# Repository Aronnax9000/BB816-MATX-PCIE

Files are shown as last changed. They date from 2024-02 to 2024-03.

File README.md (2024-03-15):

# BB816-PCIe
Adapt Adrien Kohlbecker's BB816 Breakout Board to PCIExpress x16 style connector.

Four slots for expansion cards based on PCIe geometry and the mATX Specification. A 20 pin ATX power supply connector is provided. The board is made to the same specifications as Adrien Kohlbecker's BB816

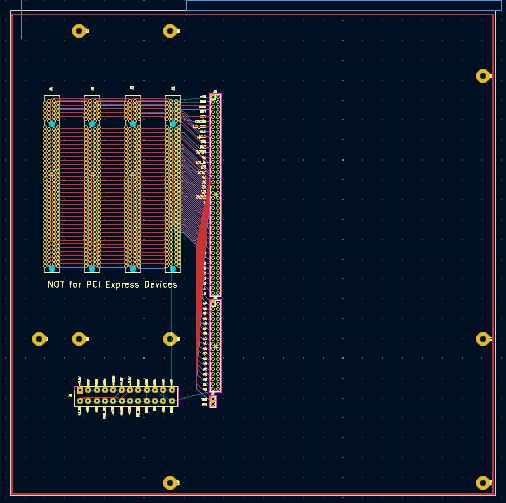
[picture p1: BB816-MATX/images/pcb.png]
Backplane


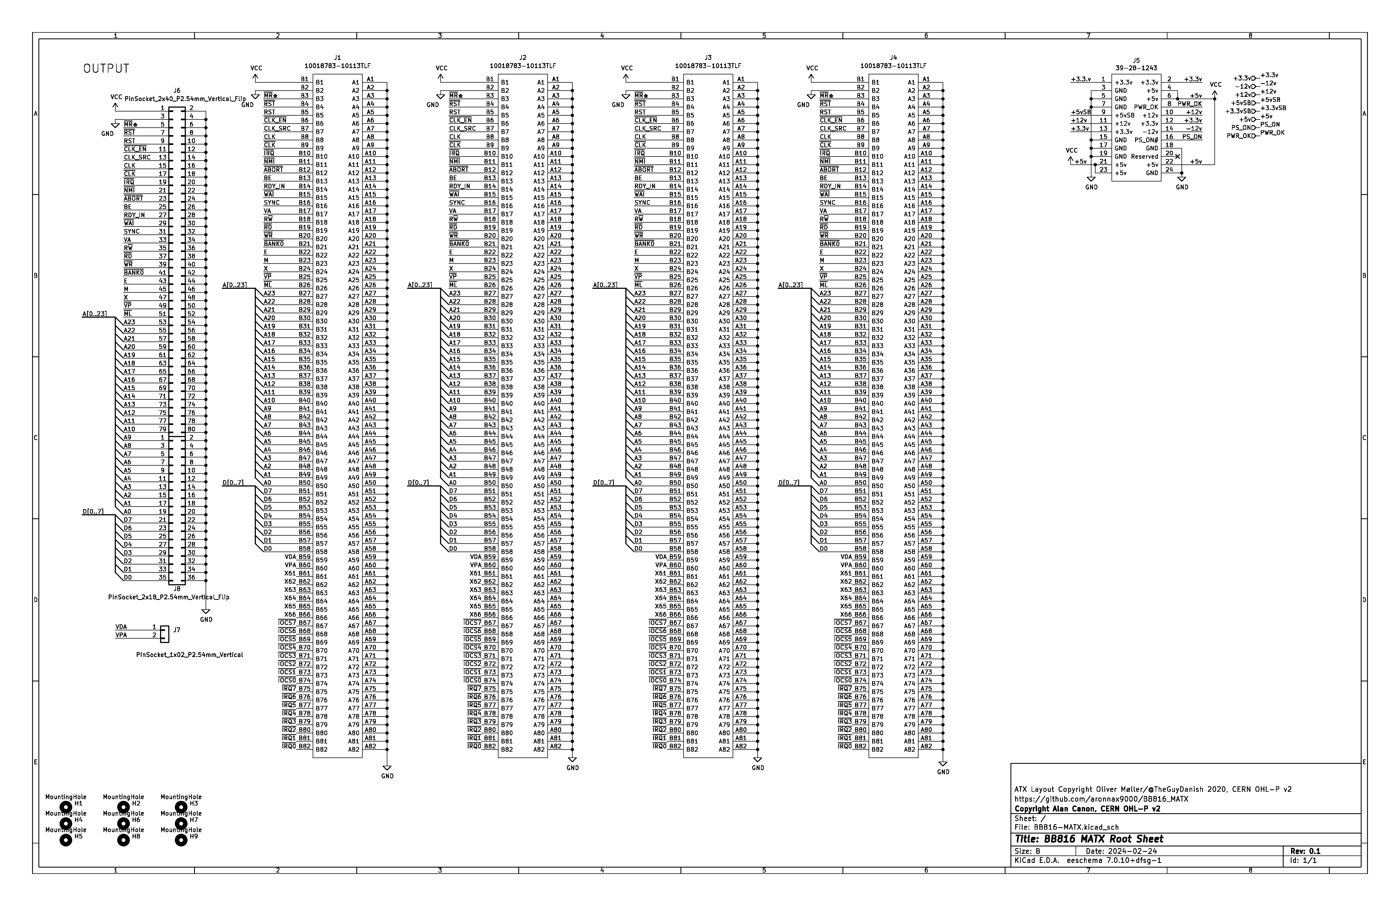
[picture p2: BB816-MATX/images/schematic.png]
Backplane Scematic


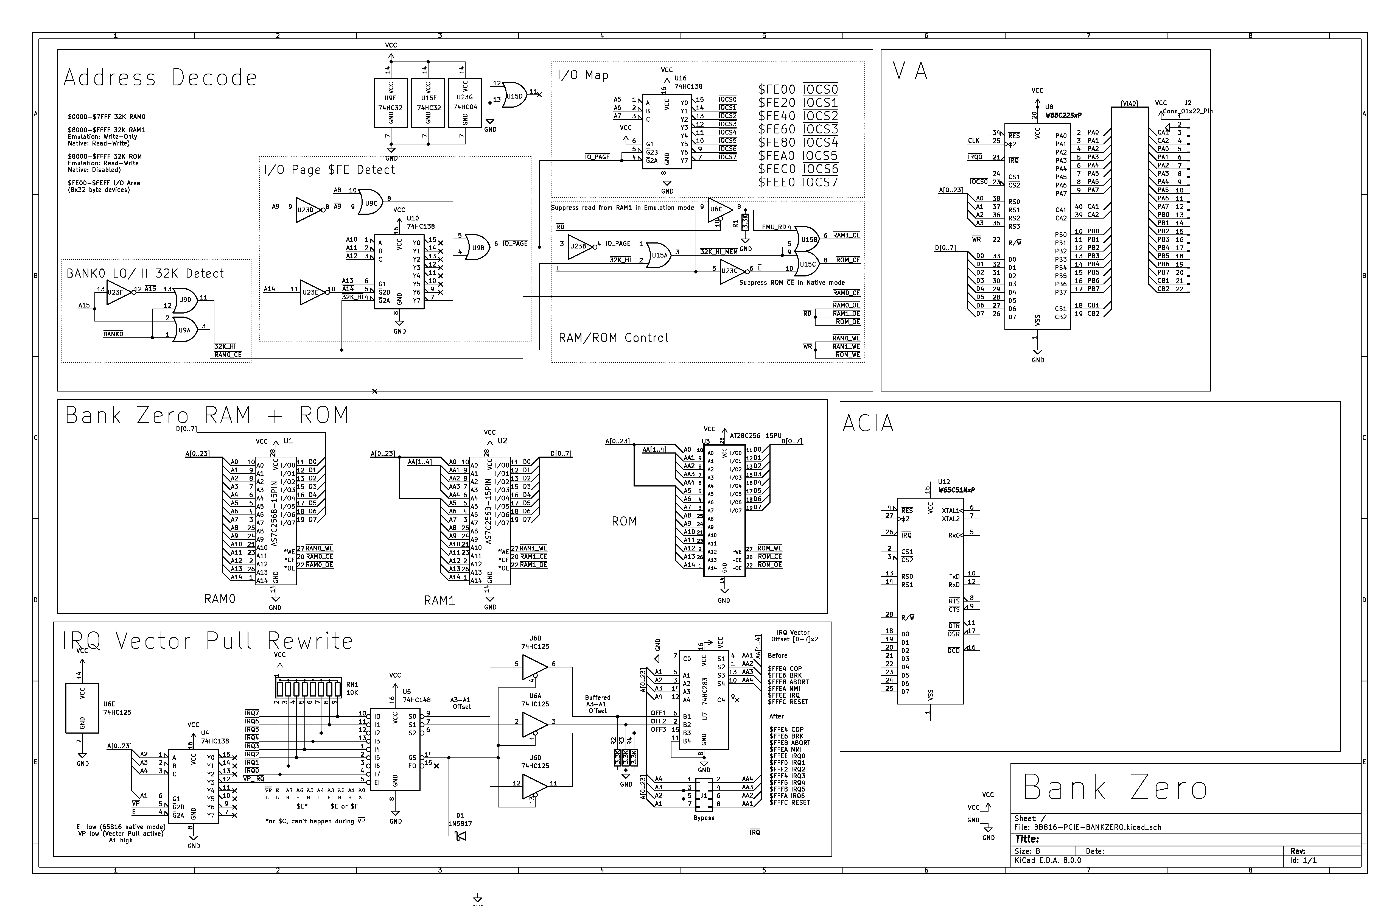
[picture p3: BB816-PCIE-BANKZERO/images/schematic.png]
Schematic


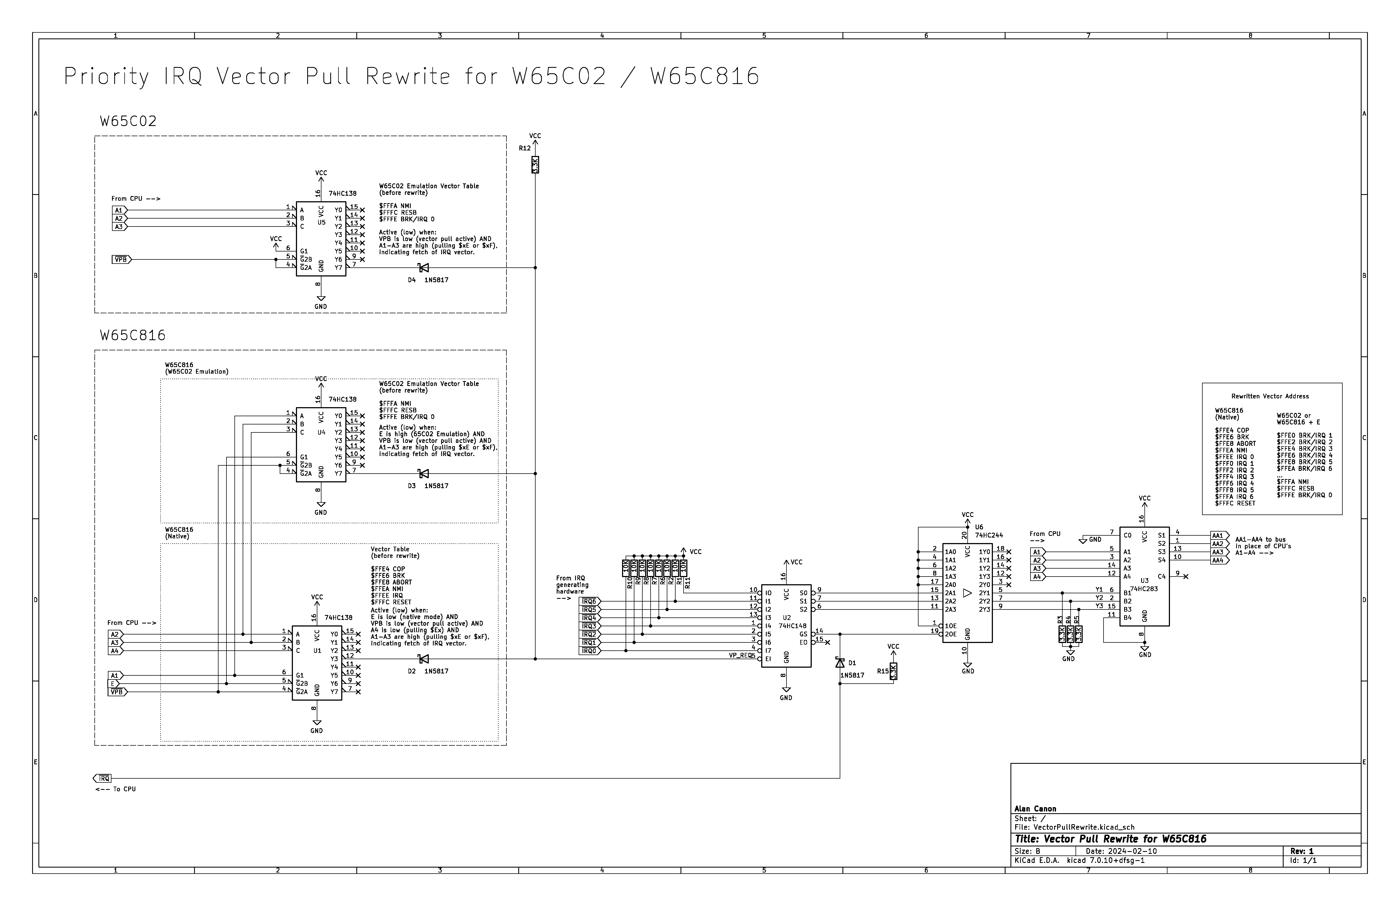
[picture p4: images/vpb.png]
VectorPullRewrite


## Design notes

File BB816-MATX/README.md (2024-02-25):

# BB816-MATX

A mATX (Micro-ATX) form factor system board for Adrien Kohlbecker's [BB816](https://github.com/adrienkohlbecker/BB816) Breakout Board, rev. A27.

This project adapts an [ATX layout](https://github.com/theguydanish/CM4_MATX) created by Oliver Møller for the (archived) CM4_MATX project.

In addition to the breakout board connector, the system board provides four bus connectors of the type used for PCIExpress x16 add-on cards, and an ATX power supply connector. 

Schematic

PCB

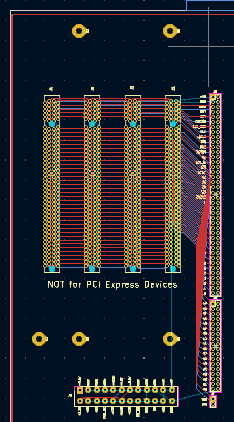
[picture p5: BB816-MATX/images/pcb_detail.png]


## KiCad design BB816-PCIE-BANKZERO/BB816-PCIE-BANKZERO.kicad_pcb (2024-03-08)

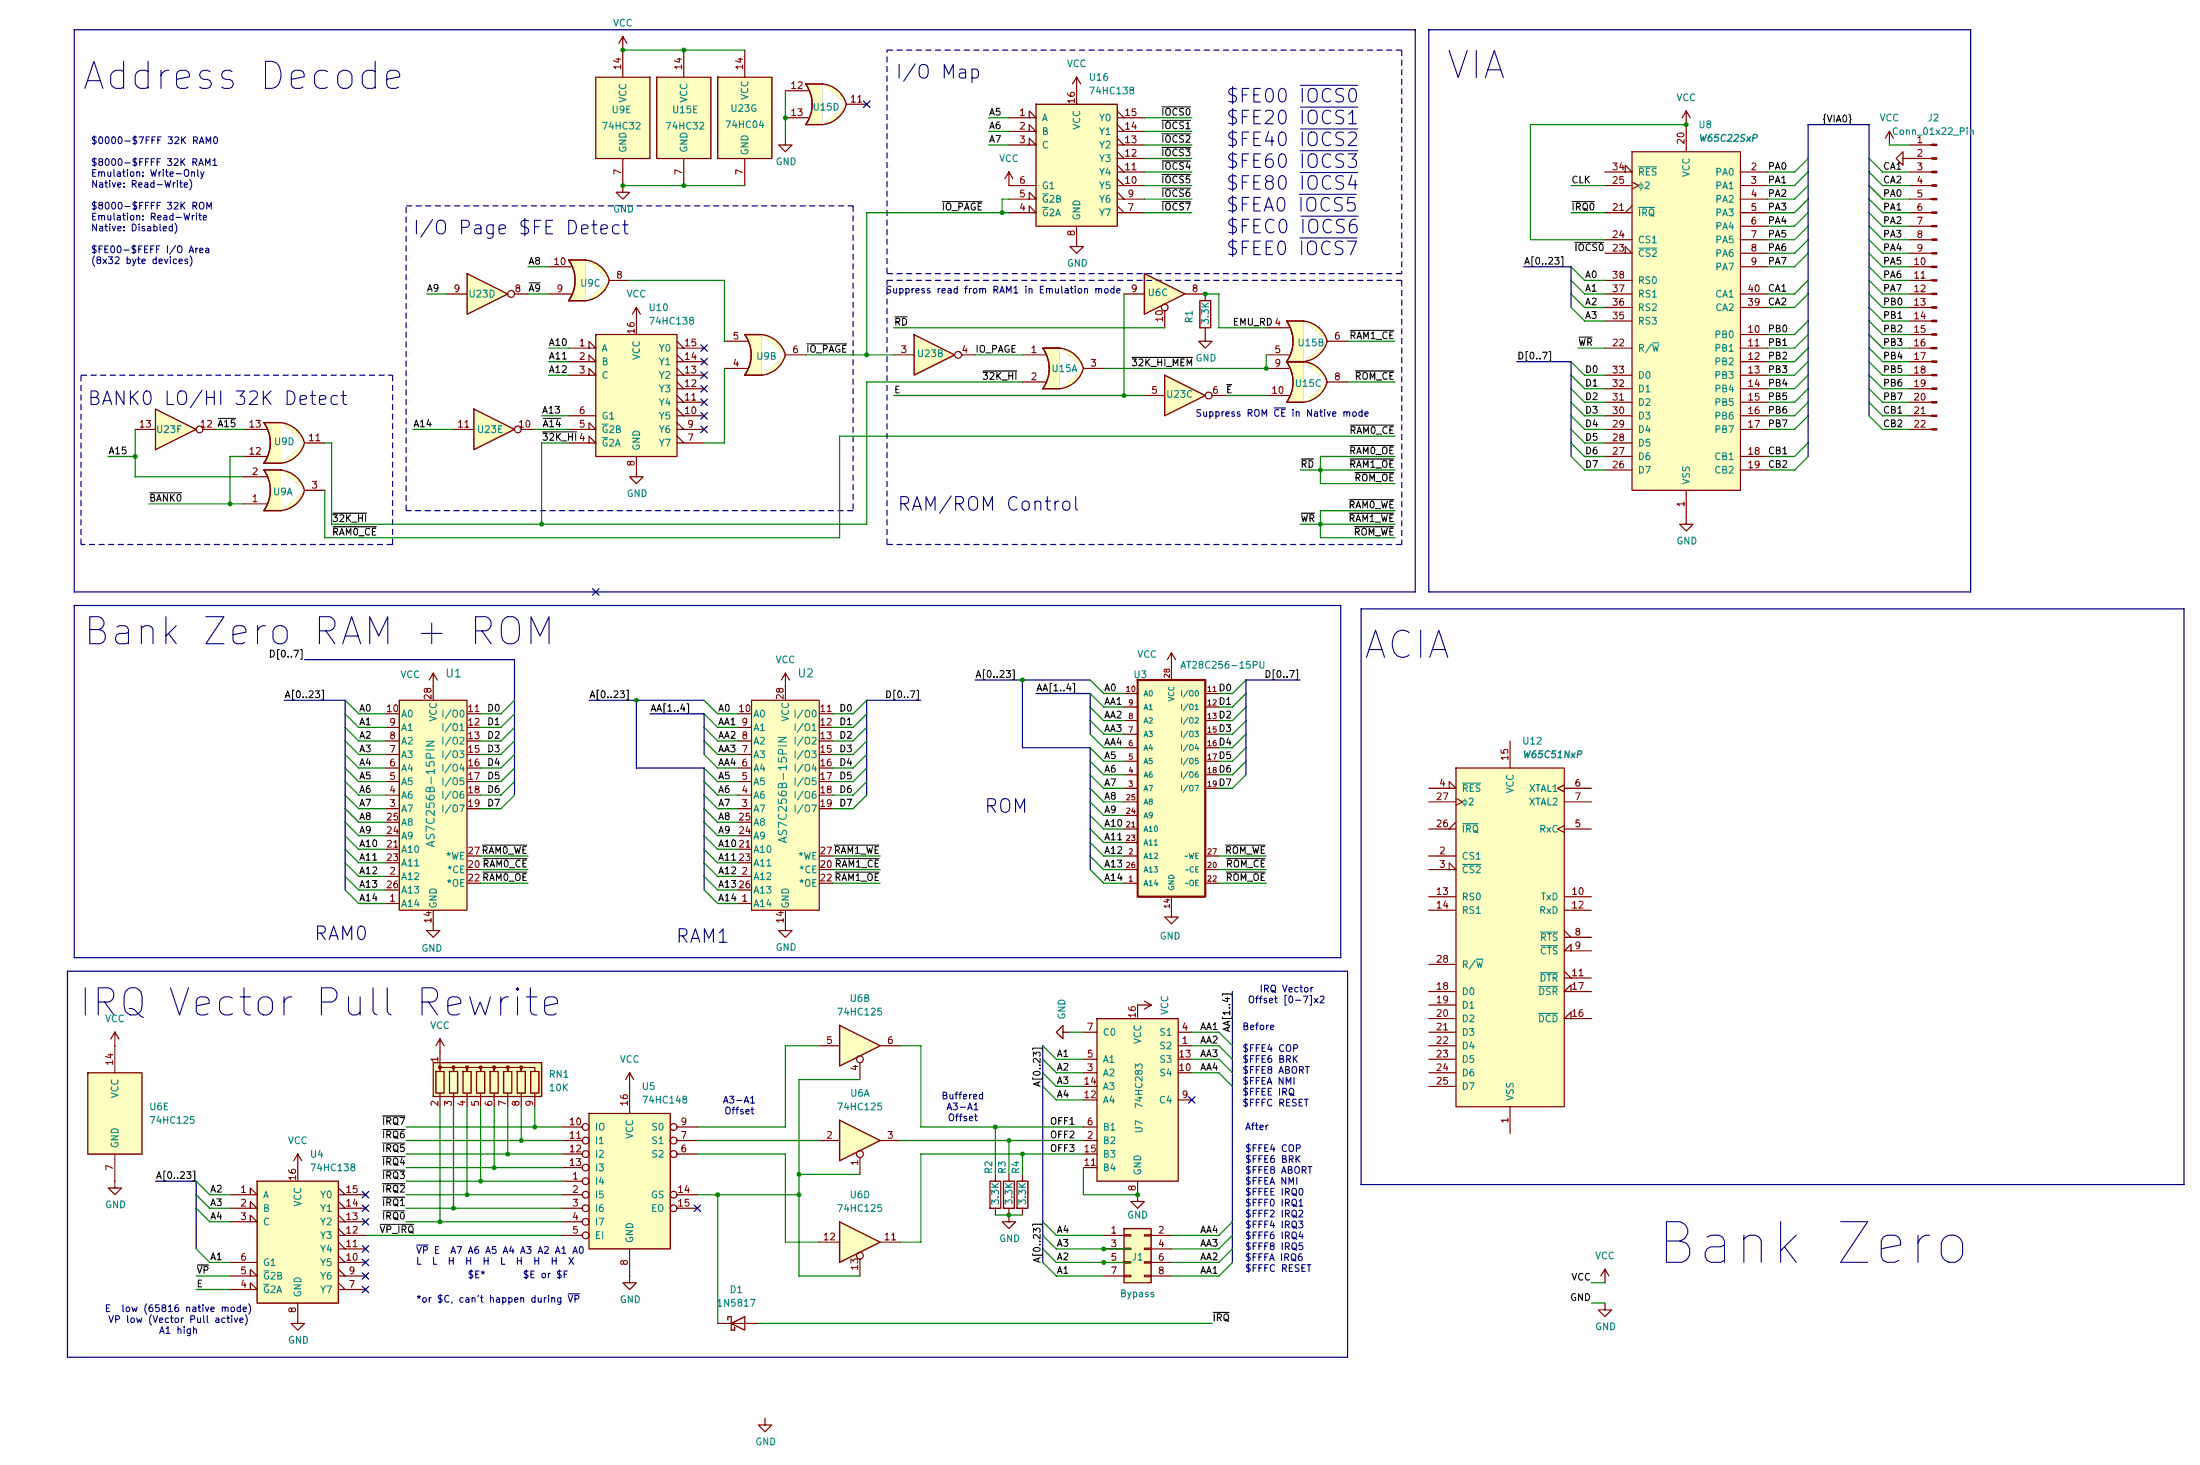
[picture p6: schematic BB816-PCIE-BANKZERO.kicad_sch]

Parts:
D1: 1N5817; D_DO-41_SOD81_P10.16mm_Horizontal
J1: Bypass; PinHeader_2x04_P2.54mm_Vertical
J2: Conn_01x22_Pin; PinSocket_1x22_P2.54mm_Horizontal
R1, R2, R3, R4: 3.3K; R_Axial_DIN0207_L6.3mm_D2.5mm_P7.62mm_Horizontal
RN1: 10K; R_Array_SIP9
U1, U2: AS7C256B-15PIN; DIP-28_W7.62mm_Socket
U3: AT28C256-15PU; 228-1277-00-0602J_3MM; MPN AT28C256-15PU
U4, U10, U16: 74HC138; DIP-16_W7.62mm_Socket
U5: 74HC148; DIP-16_W7.62mm_Socket
U6: 74HC125; DIP-14_W7.62mm_Socket
U7: 74HC283; DIP-16_W7.62mm_Socket
U8: W65C22SxP; DIP-40_W15.24mm_Socket
U9, U15: 74HC32; DIP-14_W7.62mm_Socket
U12: W65C51NxP; DIP-28_W15.24mm_Socket
U23: 74HC04; DIP-14_W7.62mm_Socket

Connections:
/A0: U1.10 (A0), U2.10 (A0), U3.10 (A0), U8.38 (RS0)
/A1: J1.7, U1.9 (A1), U4.6 (G1), U7.5 (A1), U8.37 (RS1)
/A2: J1.5, U1.8 (A2), U4.1 (A), U7.3 (A2), U8.36 (RS2)
/A3: J1.3, U1.7 (A3), U4.2 (B), U7.14 (A3), U8.35 (RS3)
/A4: J1.1, U1.6 (A4), U4.3 (C), U7.12 (A4)
/A5: U1.5 (A5), U2.5 (A5), U3.5 (A5), U16.1 (A)
/A6: U1.4 (A6), U2.4 (A6), U3.4 (A6), U16.2 (B)
/A7: U1.3 (A7), U2.3 (A7), U3.3 (A7), U16.3 (C)
/A8: U1.25 (A8), U2.25 (A8), U3.25 (A8), U9.10
/A9: U1.24 (A9), U2.24 (A9), U3.24 (A9), U23.9
/A10: U1.21 (A10), U2.21 (A10), U3.21 (A10), U10.1 (A)
/A11: U1.23 (A11), U2.23 (A11), U3.23 (A11), U10.2 (B)
/A12: U1.2 (A12), U2.2 (A12), U3.2 (A12), U10.3 (C)
/A13: U1.26 (A13), U2.26 (A13), U3.26 (A13), U10.6 (G1)
/A14: U1.1 (A14), U2.1 (A14), U3.1 (A14), U23.11
/A15: U9.2, U23.13
/AA1: J1.8, U2.9 (A1), U3.9 (A1), U7.4 (S1)
/AA2: J1.6, U2.8 (A2), U3.8 (A2), U7.1 (S2)
/AA3: J1.4, U2.7 (A3), U3.7 (A3), U7.13 (S3)
/AA4: J1.2, U2.6 (A4), U3.6 (A4), U7.10 (S4)
/CA1: J2.3, U8.40 (CA1)
/CA2: J2.4, U8.39 (CA2)
/CB1: J2.21, U8.18 (CB1)
/CB2: J2.22, U8.19 (CB2)
/CLK: U8.25 (ϕ2)
/D0: U1.11 (I/O0), U2.11 (I/O0), U3.11 (I/O0), U8.33 (D0)
/D1: U1.12 (I/O1), U2.12 (I/O1), U3.12 (I/O1), U8.32 (D1)
/D2: U1.13 (I/O2), U2.13 (I/O2), U3.13 (I/O2), U8.31 (D2)
/D3: U1.15 (I/O3), U2.15 (I/O3), U3.15 (I/O3), U8.30 (D3)
/D4: U1.16 (I/O4), U2.16 (I/O4), U3.16 (I/O4), U8.29 (D4)
/D5: U1.17 (I/O5), U2.17 (I/O5), U3.17 (I/O5), U8.28 (D5)
/D6: U1.18 (I/O6), U2.18 (I/O6), U3.18 (I/O6), U8.27 (D6)
/D7: U1.19 (I/O7), U2.19 (I/O7), U3.19 (I/O7), U8.26 (D7)
/E: U4.4 (~G2A), U6.9, U23.5
/EMU_RD: R1.1, U6.8, U15.4
/IO_PAGE: U15.1, U23.4
/OFF1: R2.1, U6.6, U7.6 (B1)
/OFF2: R3.1, U6.3, U7.2 (B2)
/OFF3: R4.1, U6.11, U7.15 (B3)
/PA0: J2.5, U8.2 (PA0)
/PA1: J2.6, U8.3 (PA1)
/PA2: J2.7, U8.4 (PA2)
/PA3: J2.8, U8.5 (PA3)
/PA4: J2.9, U8.6 (PA4)
/PA5: J2.10, U8.7 (PA5)
/PA6: J2.11, U8.8 (PA6)
/PA7: J2.12, U8.9 (PA7)
/PB0: J2.13, U8.10 (PB0)
/PB1: J2.14, U8.11 (PB1)
/PB2: J2.15, U8.12 (PB2)
/PB3: J2.16, U8.13 (PB3)
/PB4: J2.17, U8.14 (PB4)
/PB5: J2.18, U8.15 (PB5)
/PB6: J2.19, U8.16 (PB6)
/PB7: J2.20, U8.17 (PB7)
/~32K_HI_MEM: U15.3, U15.5, U15.9
/~32K_HI: U9.11, U10.4 (~G2A), U15.2
/~A9: U9.9, U23.8
/~A14: U10.5 (~G2B), U23.10
/~A15: U9.13, U23.12
/~BANK0: U9.1, U9.12
/~E: U15.10, U23.6
/~IOCS0: U8.23 (~CS2), U16.15 (Y0)
/~IOCS1: U16.14 (Y1)
/~IOCS2: U16.13 (Y2)
/~IOCS3: U16.12 (Y3)
/~IOCS4: U16.11 (Y4)
/~IOCS5: U16.10 (Y5)
/~IOCS6: U16.9 (Y6)
/~IOCS7: U16.7 (Y7)
/~IO_PAGE: U9.6, U16.4 (~G2A), U16.5 (~G2B), U23.3
/~IRQ0: RN1.2 (R1), U5.4 (I7), U8.21 (~IRQ)
/~IRQ1: RN1.3 (R2), U5.3 (I6)
/~IRQ2: RN1.4 (R3), U5.2 (I5)
/~IRQ3: RN1.5 (R4), U5.1 (I4)
/~IRQ4: RN1.6 (R5), U5.13 (I3)
/~IRQ5: RN1.7 (R6), U5.12 (I2)
/~IRQ6: RN1.8 (R7), U5.11 (I1)
/~IRQ7: RN1.9 (R8), U5.10 (IO)
/~IRQ: D1.2 (A)
/~RAM0_CE: U1.20 (*CE), U9.3
/~RAM0_OE: U1.22 (*OE), U2.22 (*OE), U3.22 (~OE), U6.10
/~RAM0_WE: U1.27 (*WE), U2.27 (*WE), U3.27 (~WE), U8.22 (R/~W)
/~RAM1_CE: U2.20 (*CE), U15.6
/~ROM_CE: U3.20 (~CE), U15.8
/~VP_IRQ: U4.12 (Y3), U5.5 (EI)
/~VP: U4.5 (~G2B)
GND: J2.2, R1.2, R2.2, R3.2, R4.2, U1.14 (GND), U2.14 (GND), U3.14 (GND), U4.8 (GND), U5.8 (GND), U6.7 (GND), U7.7 (C0), U7.8 (GND), U7.11 (B4), U8.1 (VSS), U9.7 (GND), U10.8 (GND), U15.7 (GND), U15.12, U15.13, U16.8 (GND), U23.7 (GND)
unnamed: D1.1 (K), U5.14 (GS), U6.1, U6.4, U6.13
unnamed: U5.9 (S0), U6.5
unnamed: U5.7 (S1), U6.2
unnamed: U5.6 (S2), U6.12
unnamed: U9.5, U9.8
unnamed: U9.4, U10.7 (Y7)
VCC: J2.1, RN1.1 (common), U1.28 (VCC), U2.28 (VCC), U3.28 (VCC), U4.16 (VCC), U5.16 (VCC), U6.14 (VCC), U7.16 (VCC), U8.20 (VCC), U8.24 (CS1), U9.14 (VCC), U10.16 (VCC), U15.14 (VCC), U16.6 (G1), U16.16 (VCC), U23.14 (VCC)

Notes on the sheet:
$E or $F
After $FFE4 COP $FFE6 BRK $FFE8 ABORT $FFEA NMI $FFEE IRQ0 $FFF0 IRQ1 $FFF2 IRQ2 $FFF4 IRQ3 $FFF6 IRQ4 $FFF8 IRQ5 $FFFA IRQ6 $FFFC RESET
IRQ Vector Pull Rewrite
ROM
E low (65816 native mode) VP low (Vector Pull active) A1 high
RAM/ROM Control
Buffered A3-A1 Offset
Suppress ROM ~{CE} in Native mode
Before $FFE4 COP $FFE6 BRK $FFE8 ABORT $FFEA NMI $FFEE IRQ $FFFC RESET
BANK0 LO/HI 32K Detect
ACIA
Address Decode
Bank Zero RAM + ROM
$E*
~{VP} E A7 A6 A5 A4 A3 A2 A1 A0 L L H H H L H H H X
VIA
$FE00 ~{IOCS0} $FE20 ~{IOCS1} $FE40 ~{IOCS2} $FE60 ~{IOCS3} $FE80 ~{IOCS4} $FEA0 ~{IOCS5} $FEC0 ~{IOCS6} $FEE0 ~{IOCS7}
Suppress read from RAM1 in Emulation mode
RAM1
Bank Zero
A3-A1 Offset
I/O Map
I/O Page $FE Detect
*or $C, can't happen during ~{VP}
$0000-$7FFF 32K RAM0 $8000-$FFFF 32K RAM1 Emulation: Write-Only Native: Read-Write) $8000-$FFFF 32K ROM Emulation: Read-Write Native: Disabled) $FE00-$FEFF I/O Area (8x32 byte devices)
RAM0
IRQ Vector Offset [0-7]x2

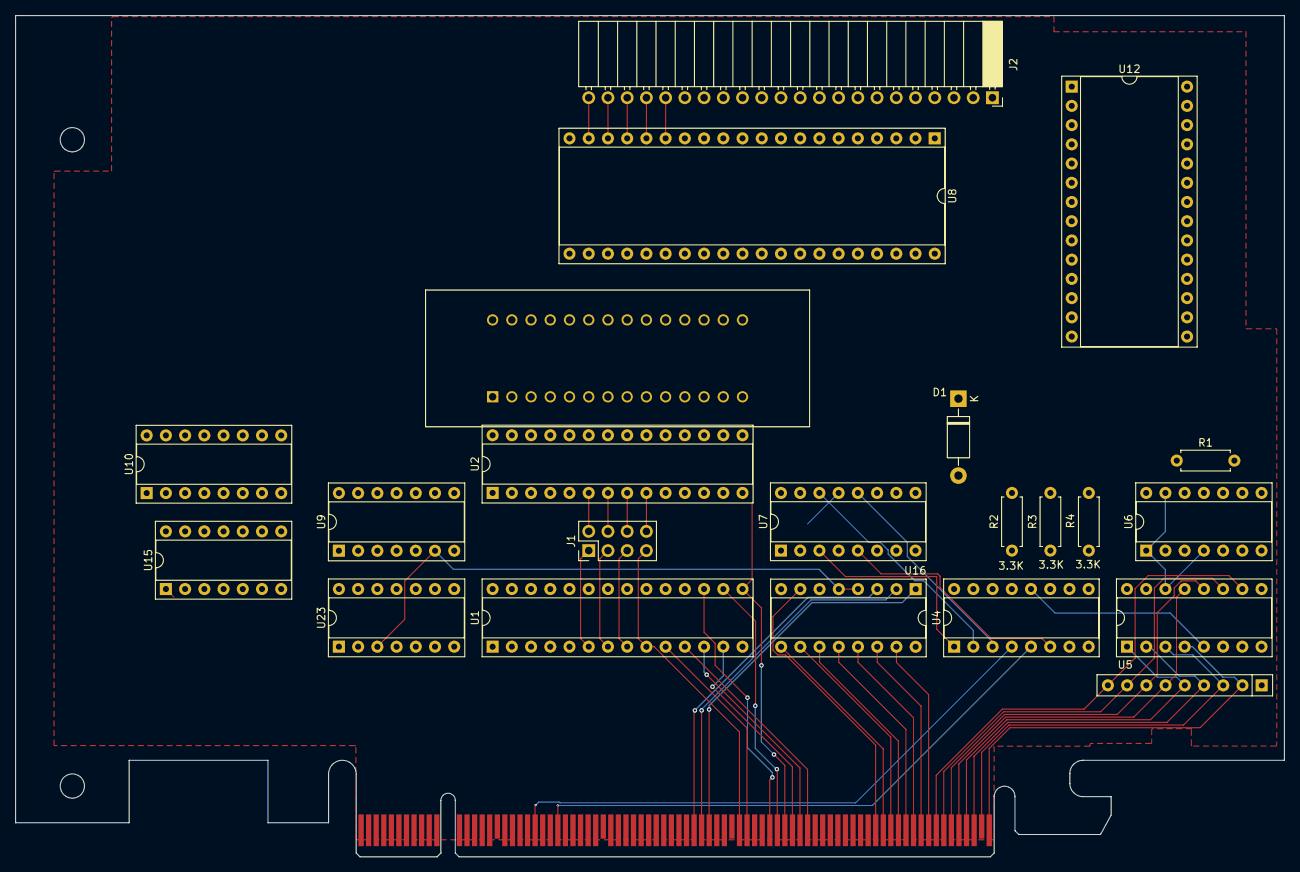
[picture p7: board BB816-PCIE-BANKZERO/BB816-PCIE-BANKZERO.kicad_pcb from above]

Board: 4 copper layers, 167.7 x 111.1 mm, 22 parts (0 on the bottom side), 85 nets.

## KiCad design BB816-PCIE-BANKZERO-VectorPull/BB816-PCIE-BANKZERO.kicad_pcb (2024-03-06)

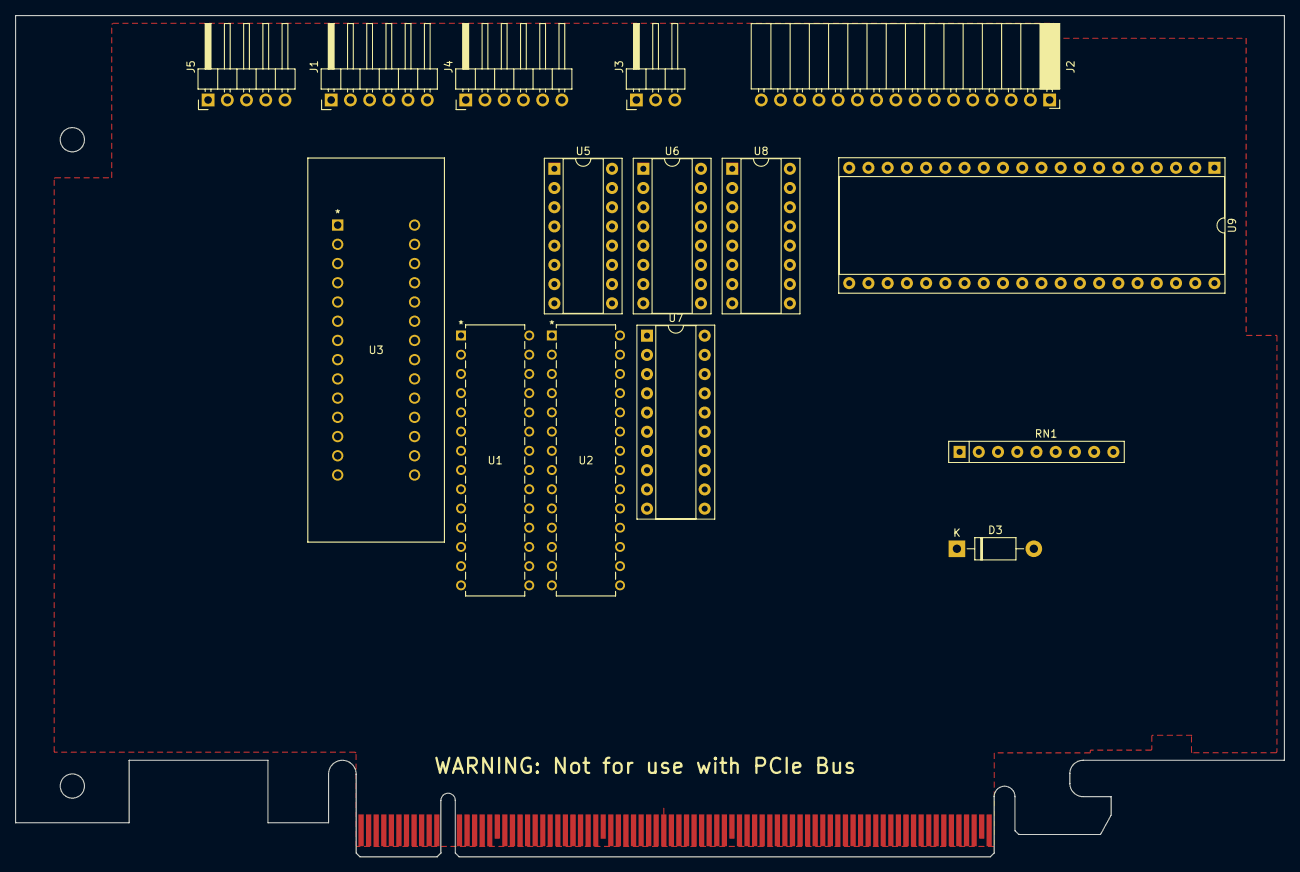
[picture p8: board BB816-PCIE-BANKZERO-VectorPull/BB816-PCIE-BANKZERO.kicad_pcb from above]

Board: 4 copper layers, 167.6 x 111.2 mm, 16 parts (0 on the bottom side), 58 nets.

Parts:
D3: 1N5817; D_DO-41_SOD81_P10.16mm_Horizontal
J1: SPI_0; PinHeader_1x06_P2.54mm_Horizontal
J1#2: BB816_BreakoutA27_PCIex16; PCIexpress_x16_HW_FH
J2: LCD Display; PinSocket_1x16_P2.54mm_Horizontal
J3: LCD Backlight; PinHeader_1x03_P2.54mm_Horizontal
J4: SPI_1; PinHeader_1x06_P2.54mm_Horizontal
J5: GPIO; PinHeader_1x05_P2.54mm_Horizontal
RN1: 10K; R_Array_SIP9
U1, U2: AS7C256B-15PIN; PDIP-28_MIL300_ALL
U3: AT28C256-15PU; 228-1277-00-0602J_3MM
U5: 74HC138; DIP-16_W7.62mm_Socket
U6: 74HC148; DIP-16_W7.62mm_Socket
U7: 74HC244; DIP-20_W7.62mm_Socket
U8: 74HC283; DIP-16_W7.62mm_Socket
U9: W65C22SxP; DIP-40_W15.24mm_Socket

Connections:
/A0: J1#2.B50 (A0), U1.10 (A0), U2.10 (A0), U3.10 (A0), U9.38 (RS0)
/A1: J1#2.B49 (A1), U1.9 (A1), U5.6 (G1), U8.5 (A1), U9.37 (RS1)
/A2: J1#2.B48 (A2), U1.8 (A2), U5.1 (A), U8.3 (A2), U9.36 (RS2)
/A3: J1#2.B47 (A3), U1.7 (A3), U5.2 (B), U8.14 (A3), U9.35 (RS3)
/A4: J1#2.B46 (A4), U1.6 (A4), U5.3 (C), U8.12 (A4)
/A5: J1#2.B45 (A5), U1.5 (A5), U2.5 (A5), U3.5 (A5)
/A6: J1#2.B44 (A6), U1.4 (A6), U2.4 (A6), U3.4 (A6)
/A7: J1#2.B43 (A7), U1.3 (A7), U2.3 (A7), U3.3 (A7)
/A8: J1#2.B42 (A8), U1.25 (A8), U2.25 (A8), U3.25 (A8)
/A9: J1#2.B41 (A9), U1.24 (A9), U2.24 (A9), U3.24 (A9)
/A10: J1#2.B40 (A10), U1.21 (A10), U2.21 (A10), U3.21 (A10)
/A11: J1#2.B39 (A11), U1.23 (A11), U2.23 (A11), U3.23 (A11)
/A12: J1#2.B38 (A12), U1.2 (A12), U2.2 (A12), U3.2 (A12)
/A13: J1#2.B37 (A13), U1.26 (A13), U2.26 (A13), U3.26 (A13)
/A14: J1#2.B36 (A14), U1.1 (A14), U2.1 (A14), U3.1 (A14)
/AA1: U2.9 (A1), U3.9 (A1), U8.4 (S1)
/AA2: U2.8 (A2), U3.8 (A2), U8.1 (S2)
/AA3: U2.7 (A3), U3.7 (A3), U8.13 (S3)
/AA4: U2.6 (A4), U3.6 (A4), U8.10 (S4)
/CLK: J1#2.B8 (CLK), U9.25 (ϕ2)
/D0: J1#2.B58 (D0), U1.11 (I/O0), U2.11 (I/O0), U3.19 (I/O7), U9.33 (D0)
/D1: J1#2.B57 (D1), U1.12 (I/O1), U2.12 (I/O1), U3.18 (I/O6), U9.32 (D1)
/D2: J1#2.B56 (D2), U1.13 (I/O2), U2.13 (I/O2), U3.17 (I/O5), U9.31 (D2)
/D3: J1#2.B55 (D3), U1.15 (I/O3), U2.15 (I/O3), U3.16 (I/O4), U9.30 (D3)
/D4: J1#2.B54 (D4), U1.16 (I/O4), U2.16 (I/O4), U3.15 (I/O3), U9.29 (D4)
/D5: J1#2.B53 (D5), U1.17 (I/O5), U2.17 (I/O5), U3.13 (I/O2), U9.28 (D5)
/D6: J1#2.B52 (D6), U1.18 (I/O6), U2.18 (I/O6), U3.12 (I/O1), U9.27 (D6)
/D7: J1#2.B51 (D7), U1.19 (I/O7), U2.19 (I/O7), U3.11 (I/O0), U9.26 (D7)
/E: J1#2.B22 (E), U5.5 (~G2B)
/PB0: J1.3 (~CS), J2.11 (D4), U9.10 (PB0)
/PB1: J2.12 (D5), J4.3 (~CS), U9.11 (PB1)
/PB2: J1.4 (SCK), J2.13 (D6), J4.4 (SCK), U9.12 (PB2)
/PB3: J1.5 (SDI), J2.14 (D7), J4.5 (SDI), U9.13 (PB3)
/PB4: J1.6 (SDO), J2.4 (RS), J4.6 (SDO), U9.14 (PB4)
/PB5: J2.5 (R~W), J5.3, U9.15 (PB5)
/PB6: J2.6 (E), J5.4, U9.16 (PB6)
/PB7: J5.5, U9.17 (PB7)
/~IRQ0: J1#2.B82 (X82), RN1.2 (R1), U6.4 (I7)
/~IRQ1: J1#2.B81 (X81), RN1.3 (R2), U6.3 (I6)
/~IRQ2: J1#2.B80 (X80), RN1.4 (R3), U6.2 (I5)
/~IRQ3: J1#2.B79 (X79), RN1.5 (R4), U6.1 (I4)
/~IRQ4: J1#2.B78 (X78), RN1.6 (R5), U6.13 (I3)
/~IRQ5: J1#2.B77 (X77), RN1.7 (R6), U6.12 (I2)
/~IRQ6: J1#2.B76 (X76), RN1.8 (R7), U6.11 (I1)
/~IRQ7: J1#2.B75 (X75), RN1.9 (R8), U6.10 (IO)
/~IRQ: D3.2 (A), J1#2.B10 (~IRQ)
/~VP: J1#2.B25 (~VP), U5.4 (~G2A)
GND: J1.2 (GND), J1#2.A1 (GND), J1#2.A2 (GND), J1#2.A3 (GND), J1#2.A4 (GND), J1#2.A5 (GND), J1#2.A6 (GND), J1#2.A7 (GND), J1#2.A8 (GND), J1#2.A9 (GND), J1#2.A10 (GND), J1#2.A11 (GND), J1#2.A12 (GND), J1#2.A13 (GND), J1#2.A14 (GND), J1#2.A15 (GND), J1#2.A16 (GND), J1#2.A17 (GND), J1#2.A18 (GND), J1#2.A19 (GND), J1#2.A20 (GND), J1#2.A21 (GND), J1#2.A22 (GND), J1#2.A23 (GND), J1#2.A24 (GND), J1#2.A25 (GND), J1#2.A26 (GND), J1#2.A27 (GND), J1#2.A28 (GND), J1#2.A29 (GND), J1#2.A30 (GND), J1#2.A31 (GND), J1#2.A32 (GND), J1#2.A33 (GND), J1#2.A34 (GND), J1#2.A35 (GND), J1#2.A36 (GND), J1#2.A37 (GND), J1#2.A38 (GND), J1#2.A39 (GND), J1#2.A40 (GND), J1#2.A41 (GND), J1#2.A42 (GND), J1#2.A43 (GND), J1#2.A44 (GND), J1#2.A45 (GND), J1#2.A46 (GND), J1#2.A47 (GND), J1#2.A48 (GND), J1#2.A49 (GND), J1#2.A50 (GND), J1#2.A51 (GND), J1#2.A52 (GND), J1#2.A53 (GND), J1#2.A54 (GND), J1#2.A55 (GND), J1#2.A56 (GND), J1#2.A57 (GND), J1#2.A58 (GND), J1#2.A59 (GND), J1#2.A60 (GND), J1#2.A61 (GND), J1#2.A62 (GND), J1#2.A63 (GND), J1#2.A64 (GND), J1#2.A65 (GND), J1#2.A66 (GND), J1#2.A67 (GND), J1#2.A68 (GND), J1#2.A69 (GND), J1#2.A70 (GND), J1#2.A71 (GND), J1#2.A72 (GND), J1#2.A73 (GND), J1#2.A74 (GND), J1#2.A75 (GND), J1#2.A76 (GND), J1#2.A77 (GND), J1#2.A78 (GND), J1#2.A79 (GND), J1#2.A80 (GND), J1#2.A81 (GND), J1#2.A82 (GND), J1#2.B2 (GND), J2.1 (VSS), J2.16 (K), J3.3 (K), J4.2 (GND), J5.2, U1.14 (GND), U2.14 (GND), U3.14 (GND), U5.8 (GND), U6.8 (GND), U7.10 (GND), U8.7 (C0), U8.8 (GND), U8.11 (B4), U9.1 (VSS)
unnamed: D3.1 (K), U6.14 (GS)
unnamed: J2.3 (V0), J3.2 (V0)
unnamed: U5.12 (Y3), U6.5 (EI)
unnamed: U6.9 (S0), U7.15 (2A1)
unnamed: U6.7 (S1), U7.13 (2A2)
unnamed: U6.6 (S2), U7.11 (2A3)
unnamed: U7.5 (2Y1), U8.6 (B1)
unnamed: U7.7 (2Y2), U8.2 (B2)
unnamed: U7.9 (2Y3), U8.15 (B3)
VCC: J1.1 (VCC), J1#2.B1 (VCC), J2.2 (VDD), J2.15 (A), J3.1 (A), J4.1 (VCC), J5.1, U1.28 (VCC), U2.28 (VCC), U3.28 (VCC), U5.16 (VCC), U6.16 (VCC), U7.1 (1OE), U7.2 (1A0), U7.4 (1A1), U7.6 (1A2), U7.8 (1A3), U7.17 (2A0), U7.20 (VCC), U8.16 (VCC), U9.20 (VCC)

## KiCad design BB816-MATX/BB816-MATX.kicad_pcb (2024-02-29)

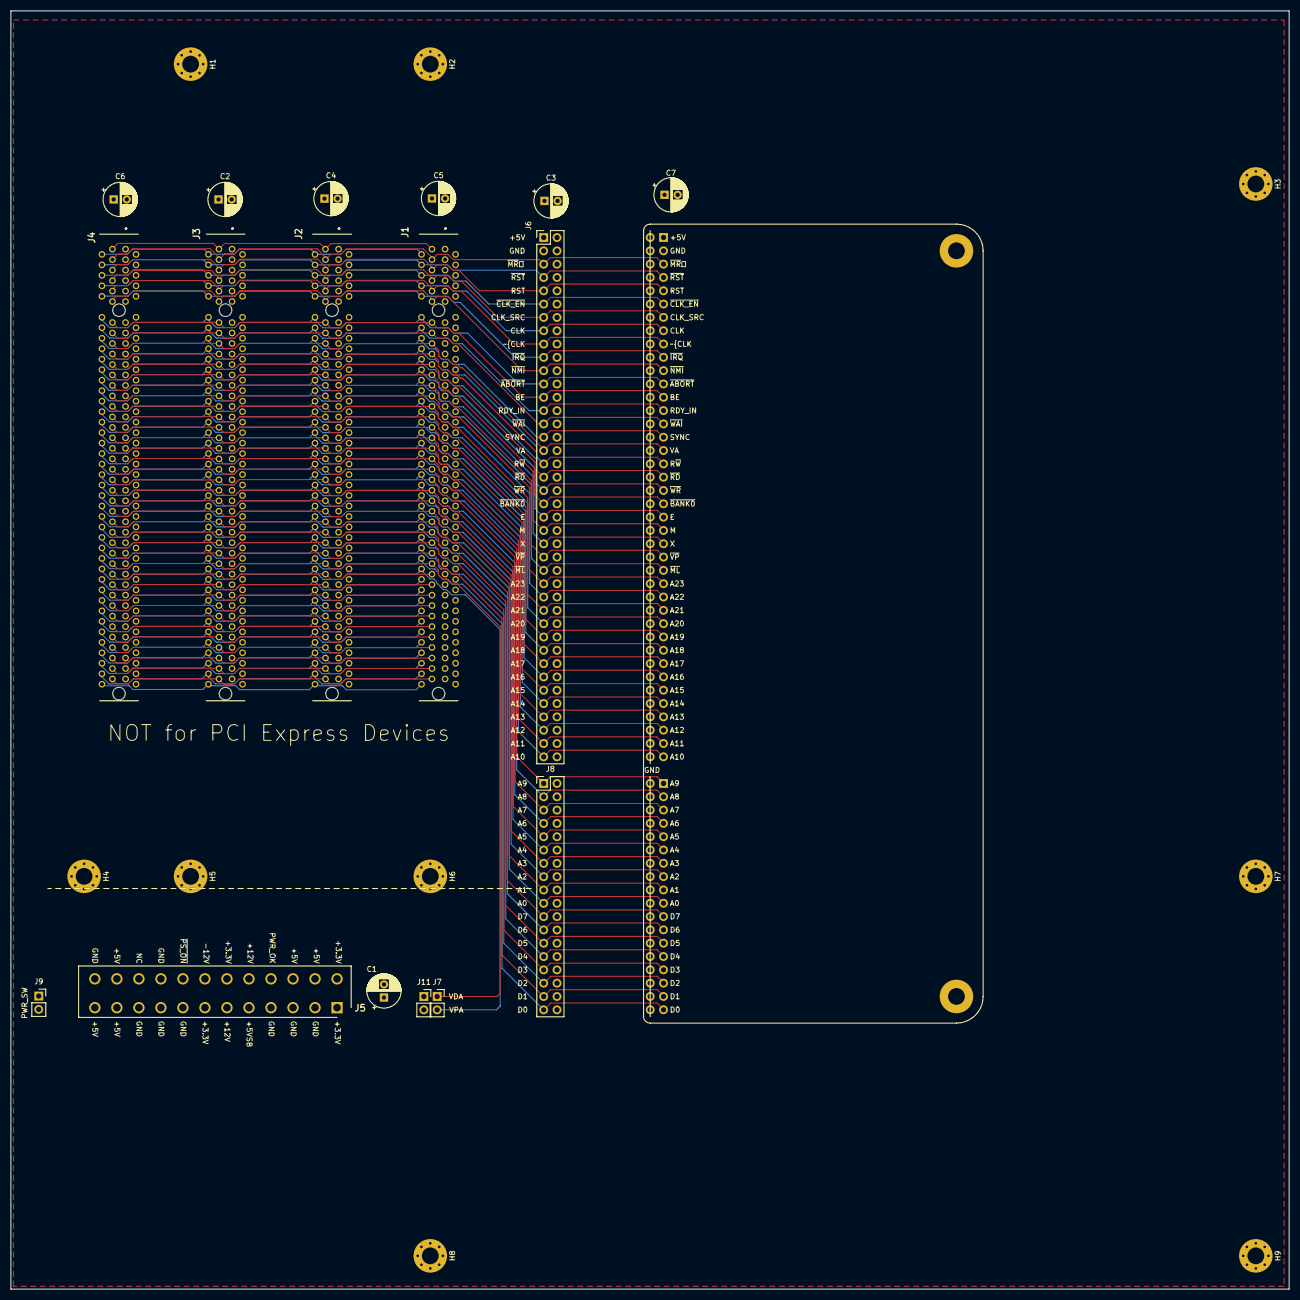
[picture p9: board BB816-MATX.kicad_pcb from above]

Board: 4 copper layers, 243.8 x 243.8 mm, 27 parts (0 on the bottom side), 85 nets.

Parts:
C1, C2, C3, C4, C5, C6, C7: 220u; CP_Radial_D6.3mm_P2.50mm
H1, H2, H3, H4, H5, H6, H7, H8, H9: MountingHole; MountingHole_3.2mm_M3_Pad_Via
J1, J2, J3, J4: 10018783-10113TLF
J5: 39-28-1243; SHDR24W125P550X420_2X12_5160X960X1310P
J6: PinSocket_2x40_P2.54mm_Vertical_Flip
J7, J11: PinSocket_1x02_P2.54mm_Vertical
J8: PinSocket_2x18_P2.54mm_Vertical_Flip
J9: PWR_SW; PinSocket_1x02_P2.54mm_Vertical
J10: BB816_Breakout_A27; BB816_Breakout_A27_Socket_NO_VDPA

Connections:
/+3.3v: J5.2 (+3.3v), J5.12 (+3.3v), J5.13 (+3.3v)
/+12v: J5.10 (+12v), J5.11 (+12v)
/A0: J1.B50, J2.B50, J3.B50, J4.B50, J8.19, J10.b50 (A0)
/A1: J1.B49, J2.B49, J3.B49, J4.B49, J8.17, J10.b49 (A1)
/A2: J1.B48, J2.B48, J3.B48, J4.B48, J8.15, J10.b48 (A2)
/A3: J1.B47, J2.B47, J3.B47, J4.B47, J8.13, J10.b47 (A3)
/A4: J1.B46, J2.B46, J3.B46, J4.B46, J8.11, J10.b46 (A4)
/A5: J1.B45, J2.B45, J3.B45, J4.B45, J8.9, J10.b45 (A5)
/A6: J1.B44, J2.B44, J3.B44, J4.B44, J8.7, J10.b44 (A6)
/A7: J1.B43, J2.B43, J3.B43, J4.B43, J8.5, J10.b43 (A7)
/A8: J1.B42, J2.B42, J3.B42, J4.B42, J8.3, J10.b42 (A8)
/A9: J1.B41, J2.B41, J3.B41, J4.B41, J8.1, J10.b41 (A9)
/A10: J1.B40, J2.B40, J3.B40, J4.B40, J6.79, J10.b40 (A10)
/A11: J1.B39, J2.B39, J3.B39, J4.B39, J6.77, J10.b39 (A11)
/A12: J1.B38, J2.B38, J3.B38, J4.B38, J6.75, J10.b38 (A12)
/A13: J1.B37, J2.B37, J3.B37, J4.B37, J6.73, J10.b37 (A13)
/A14: J1.B36, J2.B36, J3.B36, J4.B36, J6.71, J10.b36 (A14)
/A15: J1.B35, J2.B35, J3.B35, J4.B35, J6.69, J10.b35 (A15)
/A16: J1.B34, J2.B34, J3.B34, J4.B34, J6.67, J10.b34 (A16)
/A17: J1.B33, J2.B33, J3.B33, J4.B33, J6.65, J10.b33 (A17)
/A18: J1.B32, J2.B32, J3.B32, J4.B32, J6.63, J10.b32 (A18)
/A19: J1.B31, J2.B31, J3.B31, J4.B31, J6.61, J10.b31 (A19)
/A20: J1.B30, J2.B30, J3.B30, J4.B30, J6.59, J10.b30 (A20)
/A21: J1.B29, J2.B29, J3.B29, J4.B29, J6.57, J10.b29 (A21)
/A22: J1.B28, J2.B28, J3.B28, J4.B28, J6.55, J10.b28 (A22)
/A23: J1.B27, J2.B27, J3.B27, J4.B27, J6.53, J10.b27 (A23)
/BE: J1.B13, J2.B13, J3.B13, J4.B13, J6.25, J10.b13 (BE)
/CLK: J1.B8, J2.B8, J3.B8, J4.B8, J6.15, J10.b8 (CLK)
/CLK_SRC: J1.B7, J2.B7, J3.B7, J4.B7, J6.13, J10.b7 (CLK_SRC)
/D0: J1.B58, J2.B58, J3.B58, J4.B58, J8.35, J10.b58 (D0)
/D1: J1.B57, J2.B57, J3.B57, J4.B57, J8.33, J10.b57 (D1)
/D2: J1.B56, J2.B56, J3.B56, J4.B56, J8.31, J10.b56 (D2)
/D3: J1.B55, J2.B55, J3.B55, J4.B55, J8.29, J10.b55 (D3)
/D4: J1.B54, J2.B54, J3.B54, J4.B54, J8.27, J10.b54 (D4)
/D5: J1.B53, J2.B53, J3.B53, J4.B53, J8.25, J10.b53 (D5)
/D6: J1.B52, J2.B52, J3.B52, J4.B52, J8.23, J10.b52 (D6)
/D7: J1.B51, J2.B51, J3.B51, J4.B51, J8.21, J10.b51 (D7)
/E: J1.B22, J2.B22, J3.B22, J4.B22, J6.43, J10.b22 (E)
/M: J1.B23, J2.B23, J3.B23, J4.B23, J6.45, J10.b23 (M)
/PS_ON: J5.16 (PS_ON#), J9.1
/RDY_IN: J1.B14, J2.B14, J3.B14, J4.B14, J6.27, J10.b14 (RDY_IN)
/RST: J1.B5, J2.B5, J3.B5, J4.B5, J6.9, J10.b5 (RST)
/R~W: J1.B18, J2.B18, J3.B18, J4.B18, J6.35, J10.b18 (R~W)
/SYNC: J1.B16, J2.B16, J3.B16, J4.B16, J6.31, J10.b16 (SYNC)
/VA: J1.B17, J2.B17, J3.B17, J4.B17, J6.33, J10.b17 (VA)
/VDA: J1.B59, J2.B59, J3.B59, J4.B59, J7.1, J11.1
/VPA: J1.B60, J2.B60, J3.B60, J4.B60, J7.2, J11.2
/X: J1.B24, J2.B24, J3.B24, J4.B24, J6.47, J10.b24 (X)
/X61: J1.B61, J2.B61, J3.B61, J4.B61
/X62: J1.B62, J2.B62, J3.B62, J4.B62
/X63: J1.B63, J2.B63, J3.B63, J4.B63
/X64: J1.B64, J2.B64, J3.B64, J4.B64
/X65: J1.B65, J2.B65, J3.B65, J4.B65
/X66: J1.B66, J2.B66, J3.B66, J4.B66
/~ABORT: J1.B12, J2.B12, J3.B12, J4.B12, J6.23, J10.b12 (~ABORT)
/~BANK0: J1.B21, J2.B21, J3.B21, J4.B21, J6.41, J10.b21 (~BANK0)
/~CLK_EN: J1.B6, J2.B6, J3.B6, J4.B6, J6.11, J10.b6 (~CLK_EN)
/~CLK: J1.B9, J2.B9, J3.B9, J4.B9, J6.17, J10.b9 (~CLK)
/~IOCS0: J1.B74, J2.B74, J3.B74, J4.B74
/~IOCS1: J1.B73, J2.B73, J3.B73, J4.B73
/~IOCS2: J1.B72, J2.B72, J3.B72, J4.B72
/~IOCS3: J1.B71, J2.B71, J3.B71, J4.B71
/~IOCS4: J1.B70, J2.B70, J3.B70, J4.B70
/~IOCS5: J1.B69, J2.B69, J3.B69, J4.B69
/~IOCS6: J1.B68, J2.B68, J3.B68, J4.B68
/~IOCS7: J1.B67, J2.B67, J3.B67, J4.B67
/~IRQ0: J1.B82, J2.B82, J3.B82, J4.B82
/~IRQ1: J1.B81, J2.B81, J3.B81, J4.B81
/~IRQ2: J1.B80, J2.B80, J3.B80, J4.B80
/~IRQ3: J1.B79, J2.B79, J3.B79, J4.B79
/~IRQ4: J1.B78, J2.B78, J3.B78, J4.B78
/~IRQ5: J1.B77, J2.B77, J3.B77, J4.B77
/~IRQ6: J1.B76, J2.B76, J3.B76, J4.B76
/~IRQ7: J1.B75, J2.B75, J3.B75, J4.B75
/~IRQ: J1.B10, J2.B10, J3.B10, J4.B10, J6.19, J10.b10 (~IRQ)
/~ML: J1.B26, J2.B26, J3.B26, J4.B26, J6.51, J10.b26 (~ML)
/~MR⎒: J1.B3, J2.B3, J3.B3, J4.B3, J6.5, J10.b3 (~MR⎒)
/~NMI: J1.B11, J2.B11, J3.B11, J4.B11, J6.21, J10.b11 (~NMI)
/~RD: J1.B19, J2.B19, J3.B19, J4.B19, J6.37, J10.b19 (~RD)
/~RST: J1.B4, J2.B4, J3.B4, J4.B4, J6.7, J10.b4 (~RST)
/~VP: J1.B25, J2.B25, J3.B25, J4.B25, J6.49, J10.b25 (~VP)
/~WAI: J1.B15, J2.B15, J3.B15, J4.B15, J6.29, J10.b15 (~WAI)
/~WR: J1.B20, J2.B20, J3.B20, J4.B20, J6.39, J10.b20 (~WR)
GND: C1.2, C2.2, C3.2, C4.2, C5.2, C6.2, C7.2, J1.A1, J1.A2, J1.A3, J1.A4, J1.A5, J1.A6, J1.A7, J1.A8, J1.A9, J1.A10, J1.A11, J1.A12, J1.A13, J1.A14, J1.A15, J1.A16, J1.A17, J1.A18, J1.A19, J1.A20, J1.A21, J1.A22, J1.A23, J1.A24, J1.A25, J1.A26, J1.A27, J1.A28, J1.A29, J1.A30, J1.A31, J1.A32, J1.A33, J1.A34, J1.A35, J1.A36, J1.A37, J1.A38, J1.A39, J1.A40, J1.A41, J1.A42, J1.A43, J1.A44, J1.A45, J1.A46, J1.A47, J1.A48, J1.A49, J1.A50, J1.A51, J1.A52, J1.A53, J1.A54, J1.A55, J1.A56, J1.A57, J1.A58, J1.A59, J1.A60, J1.A61, J1.A62, J1.A63, J1.A64, J1.A65, J1.A66, J1.A67, J1.A68, J1.A69, J1.A70, J1.A71, J1.A72, J1.A73, J1.A74, J1.A75, J1.A76, J1.A77, J1.A78, J1.A79, J1.A80, J1.A81, J1.A82, J1.B2, J2.A1, J2.A2, J2.A3, J2.A4, J2.A5, J2.A6, J2.A7, J2.A8, J2.A9, J2.A10, J2.A11, J2.A12, J2.A13, J2.A14, J2.A15, J2.A16, J2.A17, J2.A18, J2.A19, J2.A20, J2.A21, J2.A22, J2.A23, J2.A24, J2.A25, J2.A26, J2.A27, J2.A28, J2.A29, J2.A30, J2.A31, J2.A32, J2.A33, J2.A34, J2.A35, J2.A36, J2.A37, J2.A38, J2.A39, J2.A40, J2.A41, J2.A42, J2.A43, J2.A44, J2.A45, J2.A46, J2.A47, J2.A48, J2.A49, J2.A50, J2.A51, J2.A52, J2.A53, J2.A54, J2.A55, J2.A56, J2.A57, J2.A58, J2.A59, J2.A60, J2.A61, J2.A62, J2.A63, J2.A64, J2.A65, J2.A66, J2.A67, J2.A68, J2.A69, J2.A70, J2.A71, J2.A72, J2.A73, J2.A74, J2.A75, J2.A76, J2.A77, J2.A78, J2.A79, J2.A80, J2.A81, J2.A82, J2.B2, J3.A1, J3.A2, J3.A3, J3.A4, J3.A5, J3.A6, J3.A7, J3.A8, J3.A9, J3.A10, J3.A11, J3.A12, J3.A13, J3.A14, J3.A15, J3.A16, J3.A17, J3.A18, J3.A19, J3.A20, J3.A21, J3.A22, J3.A23, J3.A24, J3.A25, J3.A26, J3.A27, J3.A28, J3.A29, J3.A30, J3.A31, J3.A32, J3.A33, J3.A34, J3.A35, J3.A36, J3.A37, J3.A38, J3.A39, J3.A40, J3.A41, J3.A42, J3.A43, J3.A44, J3.A45, J3.A46, J3.A47, J3.A48, J3.A49, J3.A50, J3.A51, J3.A52, J3.A53, J3.A54, J3.A55, J3.A56, J3.A57, J3.A58, J3.A59, J3.A60, J3.A61, J3.A62, J3.A63, J3.A64, J3.A65, J3.A66, J3.A67, J3.A68, J3.A69, J3.A70, J3.A71, J3.A72, J3.A73, J3.A74, J3.A75, J3.A76, J3.A77, J3.A78, J3.A79, J3.A80, J3.A81, J3.A82, J3.B2, J4.A1, J4.A2, J4.A3, J4.A4, J4.A5, J4.A6, J4.A7, J4.A8, J4.A9, J4.A10, J4.A11, J4.A12, J4.A13, J4.A14, J4.A15, J4.A16, J4.A17, J4.A18, J4.A19, J4.A20, J4.A21, J4.A22, J4.A23, J4.A24, J4.A25, J4.A26, J4.A27, J4.A28, J4.A29, J4.A30, J4.A31, J4.A32, J4.A33, J4.A34, J4.A35, J4.A36, J4.A37, J4.A38, J4.A39, J4.A40, J4.A41, J4.A42, J4.A43, J4.A44, J4.A45, J4.A46, J4.A47, J4.A48, J4.A49, J4.A50, J4.A51, J4.A52, J4.A53, J4.A54, J4.A55, J4.A56, J4.A57, J4.A58, J4.A59, J4.A60, J4.A61, J4.A62, J4.A63, J4.A64, J4.A65, J4.A66, J4.A67, J4.A68, J4.A69, J4.A70, J4.A71, J4.A72, J4.A73, J4.A74, J4.A75, J4.A76, J4.A77, J4.A78, J4.A79, J4.A80, J4.A81, J4.A82, J4.B2, J5.3 (GND), J5.5 (GND), J5.7 (GND), J5.15 (GND), J5.17 (GND), J5.18 (GND), J5.19 (GND), J5.24 (GND), J6.2, J6.3, J6.4, J6.6, J6.8, J6.10, J6.12, J6.14, J6.16, J6.18, J6.20, J6.22, J6.24, J6.26, J6.28, J6.30, J6.32, J6.34, J6.36, J6.38, J6.40, J6.42, J6.44, J6.46, J6.48, J6.50, J6.52, J6.54, J6.56, J6.58, J6.60, J6.62, J6.64, J6.66, J6.68, J6.70, J6.72, J6.74, J6.76, J6.78, J6.80, J8.2, J8.4, J8.6, J8.8, J8.10, J8.12, J8.14, J8.16, J8.18, J8.20, J8.22, J8.24, J8.26, J8.28, J8.30, J8.32, J8.34, J8.36, J9.2, J10.a2 (GND), J10.a3 (GND), J10.a4 (GND), J10.a5 (GND), J10.a6 (GND), J10.a7 (GND), J10.a8 (GND), J10.a9 (GND), J10.a10 (GND), J10.a11 (GND), J10.a12 (GND), J10.a13 (GND), J10.a14 (GND), J10.a15 (GND), J10.a16 (GND), J10.a17 (GND), J10.a18 (GND), J10.a19 (GND), J10.a20 (GND), J10.a21 (GND), J10.a22 (GND), J10.a23 (GND), J10.a24 (GND), J10.a25 (GND), J10.a26 (GND), J10.a27 (GND), J10.a28 (GND), J10.a29 (GND), J10.a30 (GND), J10.a31 (GND), J10.a32 (GND), J10.a33 (GND), J10.a34 (GND), J10.a35 (GND), J10.a36 (GND), J10.a37 (GND), J10.a38 (GND), J10.a39 (GND), J10.a40 (GND), J10.a41 (GND), J10.a42 (GND), J10.a43 (GND), J10.a44 (GND), J10.a45 (GND), J10.a46 (GND), J10.a47 (GND), J10.a48 (GND), J10.a49 (GND), J10.a50 (GND), J10.a51 (GND), J10.a52 (GND), J10.a53 (GND), J10.a54 (GND), J10.a55 (GND), J10.a56 (GND), J10.a57 (GND), J10.a58 (GND), J10.b2 (GND)
VCC: C1.1, C2.1, C3.1, C4.1, C5.1, C6.1, C7.1, J1.B1, J2.B1, J3.B1, J4.B1, J5.4 (+5v), J5.6 (+5v), J5.21 (+5v), J5.22 (+5v), J5.23 (+5v), J6.1, J10.b1 (VCC)

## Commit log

2024-03-06 big commit
    [BB816-PCIE-BANKZERO.kicad_pcb, BB816-PCIE-BANKZERO.kicad_sch]
2024-03-06 Bum AND
    [BB816-PCIE-BANKZERO.kicad_sch]
2024-03-06 Bad PCB
    [BB816-PCIE-BANKZERO.kicad_sch]
2024-03-07 Add VIA and ACIA
    [BB816-PCIE-BANKZERO.kicad_pcb, BB816-PCIE-BANKZERO.kicad_sch, BB816-PCIE-Board.kicad_pcb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]

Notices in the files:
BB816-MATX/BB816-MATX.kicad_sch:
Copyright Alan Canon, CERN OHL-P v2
